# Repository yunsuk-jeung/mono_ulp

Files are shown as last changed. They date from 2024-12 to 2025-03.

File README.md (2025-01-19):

## n36tsu keyboard

- 36 keys
- PG1316S
- nice!view
- nice!nano
- wireless

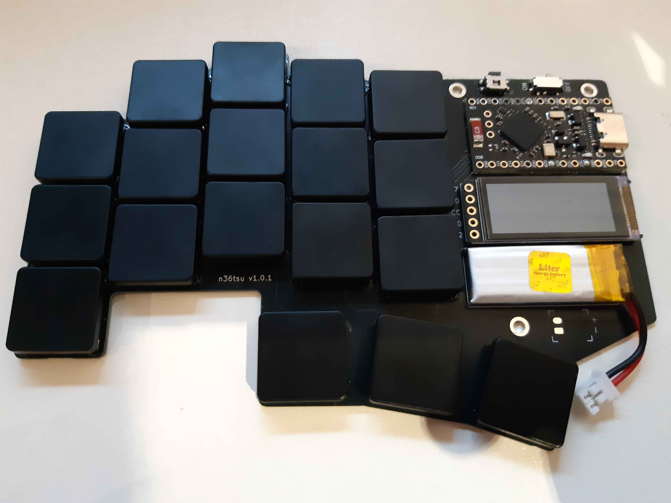
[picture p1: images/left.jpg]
left

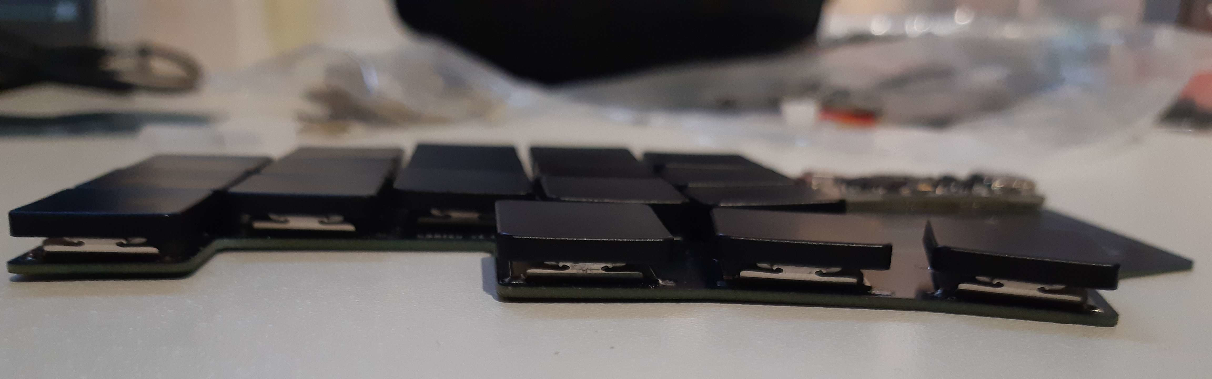
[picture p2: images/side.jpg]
side

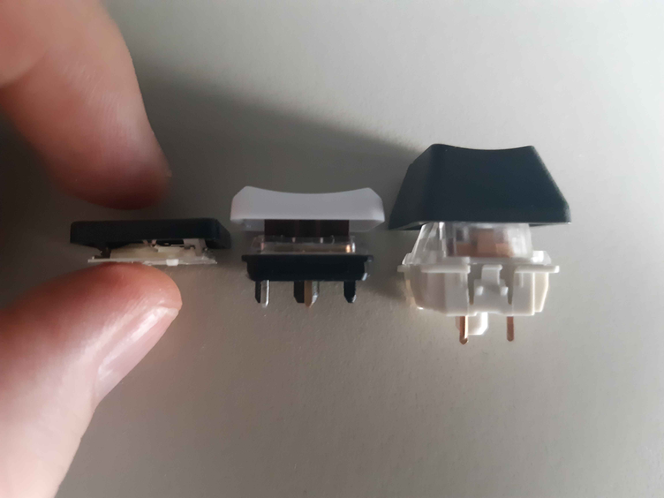
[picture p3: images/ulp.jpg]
ulp

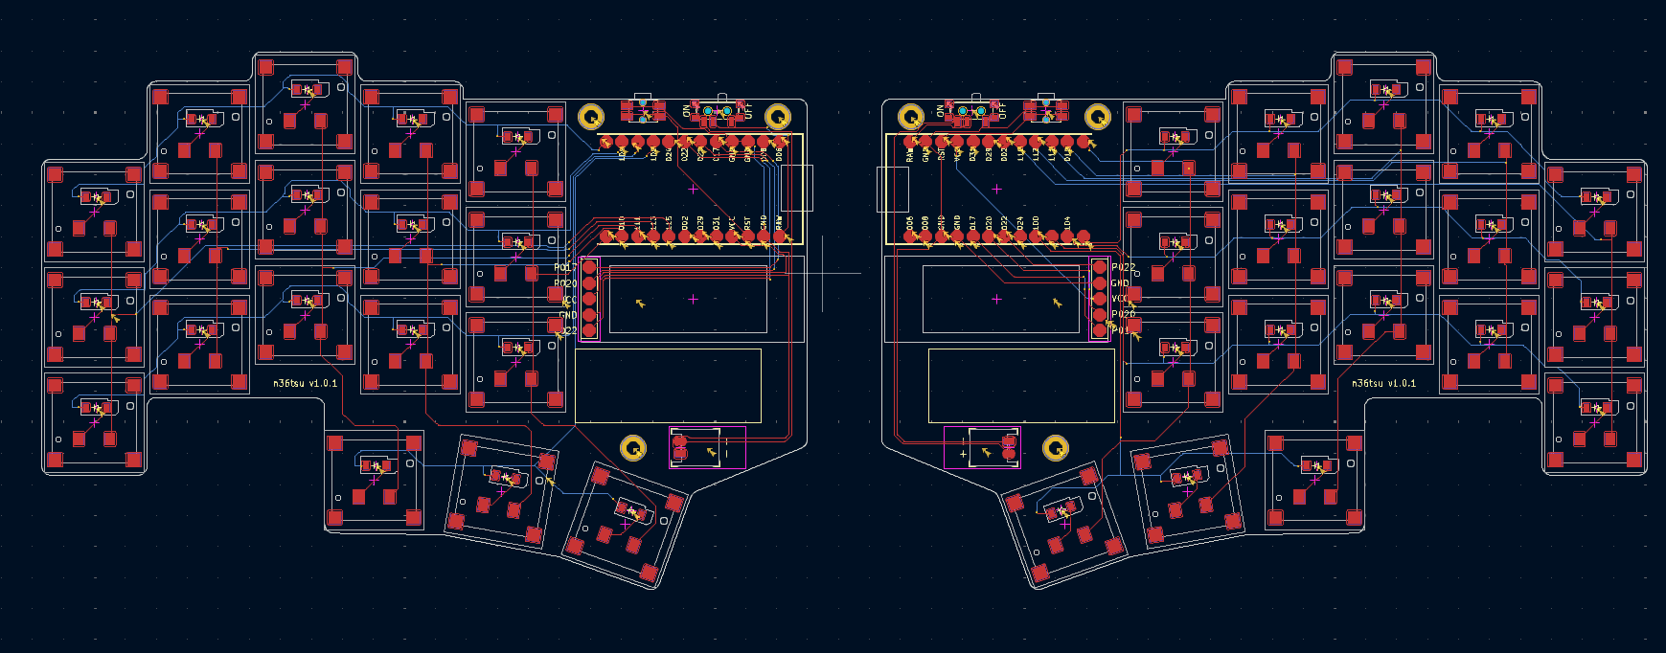
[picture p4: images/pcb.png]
PCB


## TODO

- [x] modify footprints to solder-on
- [x] verify every components orientation
- [x] add text on PCB
- [x] add case holes
- [x] wire components
- [ ] design 3D case

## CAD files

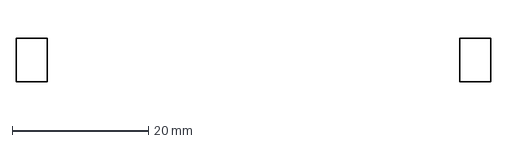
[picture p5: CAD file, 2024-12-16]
kicad/outlines/reset.dxf
69.5 x 6.40 mm

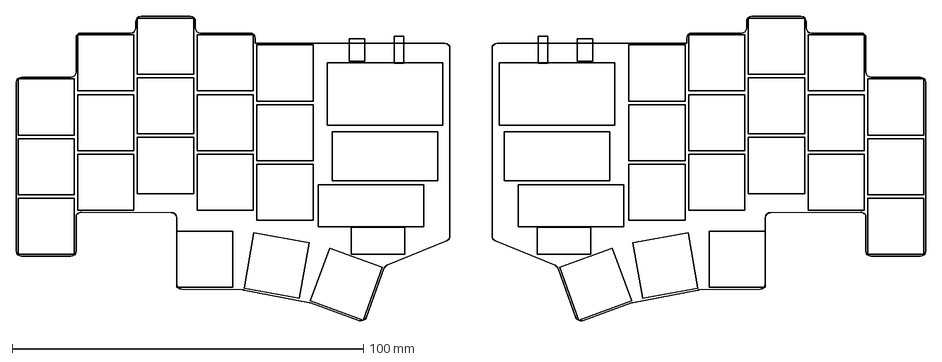
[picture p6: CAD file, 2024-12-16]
kicad/outlines/combo.dxf
259.0 x 87.0 mm

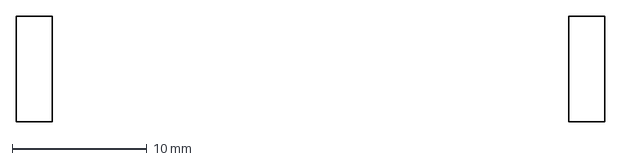
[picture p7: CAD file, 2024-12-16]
kicad/outlines/power.dxf
43.7 x 7.80 mm

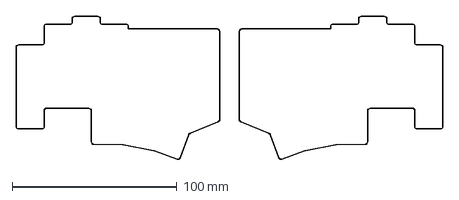
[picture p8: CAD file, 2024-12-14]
kicad/outlines/board.dxf
259.0 x 87.0 mm

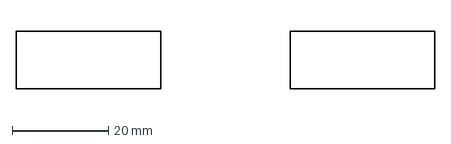
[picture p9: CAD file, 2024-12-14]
kicad/outlines/battery.dxf
87.0 x 12.0 mm

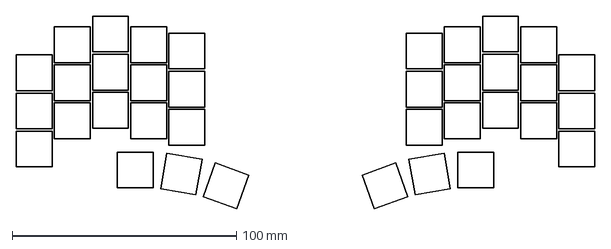
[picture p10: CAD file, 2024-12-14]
kicad/outlines/keycaps.dxf
258.0 x 86.1 mm

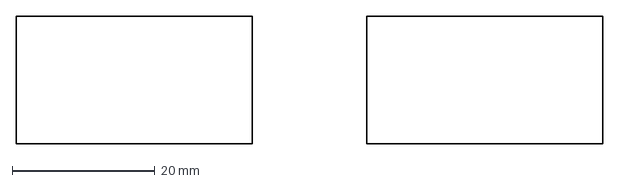
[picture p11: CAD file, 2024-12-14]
kicad/outlines/controller.dxf
82.0 x 17.8 mm

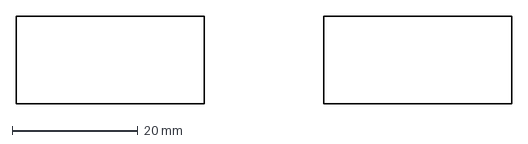
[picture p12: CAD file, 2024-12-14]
kicad/outlines/niceview.dxf
79.0 x 14.0 mm

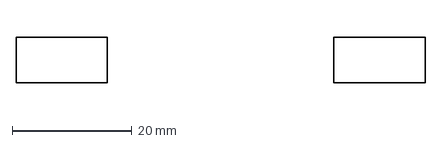
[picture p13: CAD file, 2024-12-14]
kicad/outlines/battery_connector.dxf
68.2 x 7.62 mm

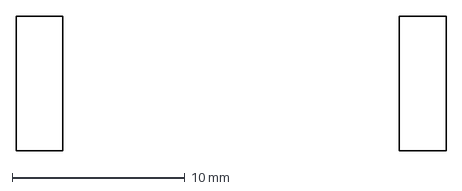
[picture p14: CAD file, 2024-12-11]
kicad/outlines/power_switch.dxf
24.9 x 7.80 mm

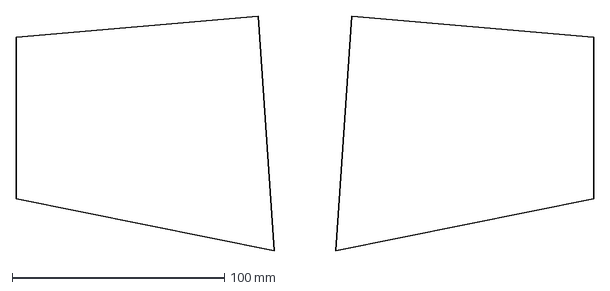
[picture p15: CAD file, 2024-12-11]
kicad/outlines/board_left.dxf
272.1 x 110.2 mm

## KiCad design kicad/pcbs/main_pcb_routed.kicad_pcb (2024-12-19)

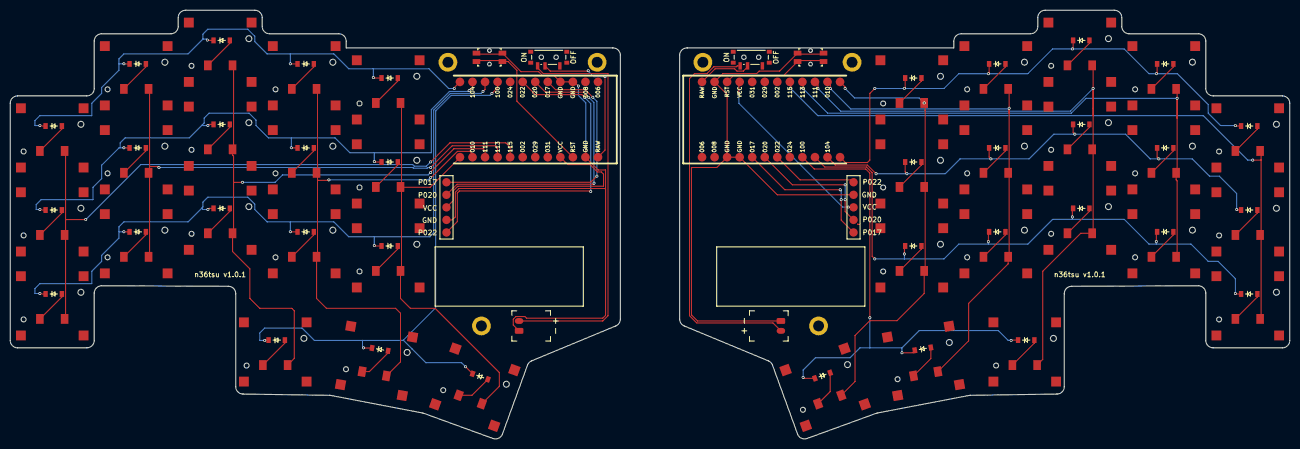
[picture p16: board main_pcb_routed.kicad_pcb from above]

Board: 2 copper layers, 259.0 x 86.8 mm, 88 parts (0 on the bottom side), 59 nets.

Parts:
D1, D2, D3, D4, D5, D6, D7, D8, D9, D10, D11, D12, D13, D14, D15, D16, D17, D18, D19, D20, D21, D22, D23, D24, D25, D26, D27, D28, D29, D30, D31, D32, D33, D34, D35, D36: diode_tht_sod123
DISP1, DISP2: display_nice_view
H1, H2, H3, H4, H5, H6: mounting_hole_plated
JST1, JST2: battery_connector_jst_ph_2
MCU1, MCU2: nice_nano
PWR1, PWR2: power_switch_smd_side
RST1, RST2: reset_switch_smd_side
S1, S2, S3, S4, S5, S6, S7, S8, S9, S10, S11, S12, S13, S14, S15, S16, S17, S18, S19, S20, S21, S22, S23, S24, S25, S26, S27, S28, S29, S30, S31, S32, S33, S34, S35, S36: CPG1316S01D02_mikeholscher

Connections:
BAT_P: JST1.2, JST2.2, PWR1.3, PWR2.3
GND: DISP1.4, DISP2.4, JST1.1, JST2.1, MCU1.3, MCU1.4, MCU1.23, MCU2.3, MCU2.4, MCU2.23, RST1.1, RST1.3, RST2.1, RST2.3
P002: MCU1.18, MCU2.18
P006: MCU1.1, MCU2.1
P008: MCU1.2, MCU2.2
P009: MCU1.13, MCU2.13, S13.2, S14.2, S15.2, S18.2, S31.2, S32.2, S33.2, S36.2
P010: MCU1.14, MCU2.14, S10.2, S11.2, S12.2, S17.2, S28.2, S29.2, S30.2, S35.2
P011: D1.1, D4.1, D7.1, D10.1, D13.1, D19.1, D22.1, D25.1, D28.1, D31.1, MCU1.10, MCU2.10
P017: DISP1.1, DISP2.1, MCU1.5, MCU2.5
P020: DISP1.2, DISP2.2, MCU1.6, MCU2.6
P022: DISP1.5, DISP2.5, MCU1.7, MCU2.7
P024: MCU1.8, MCU2.8
P029: MCU1.19, MCU2.19
P031: MCU1.20, MCU2.20
P100: D16.1, D17.1, D18.1, D34.1, D35.1, D36.1, MCU1.9, MCU2.9
P104: D2.1, D5.1, D8.1, D11.1, D14.1, D20.1, D23.1, D26.1, D29.1, D32.1, MCU1.11, MCU2.11
P106: D3.1, D6.1, D9.1, D12.1, D15.1, D21.1, D24.1, D27.1, D30.1, D33.1, MCU1.12, MCU2.12
P111: MCU1.15, MCU2.15, S7.2, S8.2, S9.2, S16.2, S25.2, S26.2, S27.2, S34.2
P113: MCU1.16, MCU2.16, S4.2, S5.2, S6.2, S22.2, S23.2, S24.2
P115: MCU1.17, MCU2.17, S1.2, S2.2, S3.2, S19.2, S20.2, S21.2
RAW: MCU1.24, MCU2.24, PWR1.2, PWR2.2
RST: MCU1.22, MCU2.22, RST1.2, RST1.4, RST2.2, RST2.4
VCC: DISP1.3, DISP2.3, MCU1.21, MCU2.21
ecolumn_arow: D8.2, S8.1
ecolumn_qrow: D9.2, S9.1
ecolumn_zrow: D7.2, S7.1
inner_default: D16.2, S16.1
middle_default: D17.2, S17.1
mirror_ecolumn_arow: D26.2, S26.1
mirror_ecolumn_qrow: D27.2, S27.1
mirror_ecolumn_zrow: D25.2, S25.1
mirror_inner_default: D34.2, S34.1
mirror_middle_default: D35.2, S35.1
mirror_outer_default: D36.2, S36.1
mirror_qcolumn_arow: D20.2, S20.1
mirror_qcolumn_qrow: D21.2, S21.1
mirror_qcolumn_zrow: D19.2, S19.1
mirror_rcolumn_arow: D29.2, S29.1
mirror_rcolumn_qrow: D30.2, S30.1
mirror_rcolumn_zrow: D28.2, S28.1
mirror_tcolumn_arow: D32.2, S32.1
mirror_tcolumn_qrow: D33.2, S33.1
mirror_tcolumn_zrow: D31.2, S31.1
mirror_wcolumn_arow: D23.2, S23.1
mirror_wcolumn_qrow: D24.2, S24.1
mirror_wcolumn_zrow: D22.2, S22.1
outer_default: D18.2, S18.1
qcolumn_arow: D2.2, S2.1
qcolumn_qrow: D3.2, S3.1
qcolumn_zrow: D1.2, S1.1
rcolumn_arow: D11.2, S11.1
rcolumn_qrow: D12.2, S12.1
rcolumn_zrow: D10.2, S10.1
tcolumn_arow: D14.2, S14.1
tcolumn_qrow: D15.2, S15.1
tcolumn_zrow: D13.2, S13.1
wcolumn_arow: D5.2, S5.1
wcolumn_qrow: D6.2, S6.1
wcolumn_zrow: D4.2, S4.1

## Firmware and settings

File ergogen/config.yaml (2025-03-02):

meta:
  engine: 4.1.0
  version: 0.0.1
  author: n1tsu

units:
  # keys
  ks: 16
  kp: 1
  kx: ks+kp
  hkx: 0.5kx
  pp: 4.9 #pcb padding
  pf: 3
  # px: 0
  qcol_stagger: 0kx
  wcol_stagger: 0.625 kx
  ecol_stagger: 0.125U
  rcol_stagger: -0.375U
  tcol_stagger: -0.125U
  thumb_splay: 0
  mirror_splay: -15
  mirror_dist: 60
  # mirror_splay: 0
  # mirror_dist: 80

  # case
  case_edge_size: 0

  # screw
  sr: 1.1 # M2 screws radius
  sd: sr * 2
  sp: sr * 2 #screw padding

  # components
  components_padding: 4
  nicenano_width: 17.78
  nicenano_height: 33
  battery_width: 12
  battery_height: 30
  niceview_width: 14
  niceview_height: 30
  battery_connector_width: 8.5 # !
  battery_connector_height: 3 # !
  power_width: 8.5
  power_height: 3
  reset_width: 8
  reset_height: 3.5

points:
  zones:
    matrix:
      key:
        spread: ks + kp
        tags: "keys"
      anchor.shift: [100, -100]
      columns:
        qcol:
          key:
            stagger: qcol_stagger
            column_net: D05
        wcol.key.stagger: wcol_stagger
        ecol.key.stagger: ecol_stagger
        rcol.key.stagger: rcol_stagger
        tcol.key.stagger: tcol_stagger
      rows:
        zrow.padding: ks + kp
        arow.padding: ks + kp
        qrow:
          padding: ks + kp
          row_net: D01
          mirror.row_net: D04

    thumb:
      key:
        tags: "keys"
        spread: ks+kp
        padding: ks+kp
      anchor:
        ref: matrix_rcol_zrow
        shift: [0, -ks-kp]
      columns:
        inner:
        middle.key:
          shift: [0, tcol_stagger]
        outer.key:
          shift: [0, tcol_stagger+tcol_stagger]

    helper_qcol_zrow_right_bottom:
      key.tags:
        - helper
      anchor:
        ref: matrix_qcol_zrow
        shift: [kx, -50]

    helper_thumb_inner_left_bottom:
      key.tags:
        - helper
      anchor:
        ref: thumb_inner
        shift: [-hkx-pp, -hkx-pp]
        rotate: 90

    helper_qcol_zrow_thumb_inter:
      key.tags:
        - helper
      anchor:
        - aggregate:
            method: intersect
            parts:
              - ref: helper_qcol_zrow_right_bottom
              - ref: helper_thumb_inner_left_bottom

    helper_tcol_qrow_unrotated:
      key.tags:
        - helper
      anchor:
        ref: matrix_tcol_qrow
        rotate: -mirror_splay

    helper_tcol_qrow_directing_right:
      key.tags:
        - helper
      anchor:
        ref: matrix_tcol_qrow
        shift: [(hkx+pp), (hkx+pp)]
        rotate: -90-mirror_splay

    center_line:
      key.tags:
        - helper
      anchor:
        ref: helper_tcol_qrow_unrotated
        shift: [0.5 mirror_dist, 50]
        rotate: 180

    controller_top_rotated:
      key.tags:
        - helper
      anchor:
        - aggregate:
            method: intersect
            parts:
              - ref: helper_tcol_qrow_directing_right
              - ref: center_line

    controller_top:
      key.tags:
        - helper
      anchor:
        ref: controller_top_rotated
        rotate: -mirror_splay

    controller_center:
      key.tags:
        - helper
      anchor:
        ref: controller_top
        shift: [0, -0.5 nicenano_height -0.5 + tcol_stagger-3]

    helper_thumb_outer_directing_right:
      key.tags:
        - helper
      anchor:
        ref: thumb_outer
        shift: [hkx+pp, hkx]
        rotate: -90-mirror_splay

    power_rotated:
      key.tags:
        - helper
      anchor:
        - aggregate:
            method: intersect
            parts:
              - ref: helper_thumb_outer_directing_right
              - ref: center_line

    power_center_bottom:
      key.tags:
        - helper
      anchor:
        ref: power_rotated
        rotate: -mirror_splay

    power_center:
      key.tags:
        - helper
      anchor:
        ref: power_center_bottom
        shift: [0, 0.5 power_height + 0.5]

    battery_center:
      key.tags:
        - helper
      anchor:
        ref: power_center
        shift: [0, 8.5]
        rotate: 90

    reset_center:
      key.tags:
        - helper
      anchor:
        ref: thumb_outer
        shift: [2, hkx + pp + reset_height]

    sc_tl:
      key.tags:
        - screw
      anchor:
        - ref: matrix_qcol_qrow
          shift: [0, hkx+pp]

    sc_tm:
      key.tags:
        - screw
      anchor:
        - ref: matrix_ecol_qrow
          shift: [0, hkx+pp-sp]
    sc_rm:
      key.tags:
        - screw
      anchor:
        - ref: matrix_tcol_qrow
          shift: [hkx+2sp, hkx-sp]
    sc_rb:
      key.tags:
        - screw
      anchor:
        - ref: thumb_outer
          shift: [hkx+pp-1.2sp, -hkx-pp+1.2sp]
    sc_rb2:
      key.tags:
        - screw
      anchor:
        - ref: thumb_inner
          shift: [-hkx-pp+1.2sp, -hkx-pp+1.2sp]
    sc_lb:
      key.tags:
        - screw
      anchor:
        - ref: matrix_qcol_zrow
          shift: [-hkx-pp+0.9pf, -hkx-pp+0.9pf]
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

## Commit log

2024-12-10 Update PG1316 footprint
2024-12-11 Add README, kicad and image
    [battery.dxf, battery_connector.dxf, board.dxf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]
2024-12-12 Adjust PCB component positions
    [battery.dxf, battery_connector.dxf, board.dxf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]
2024-12-12 Add text footprint
2024-12-14 Remove pcb border
    [battery.dxf, battery_connector.dxf, board.dxf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]
2024-12-14 Route left PCB
    [main_pcb.kicad_pcb, main_pcb_routed.kicad_pcb]
2024-12-16 Modify routing
    [combo.dxf, main_pcb.kicad_pcb, main_pcb_routed2.kicad_pcb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]
2024-12-17 Complete PCB wiring
    [main_pcb_routed.kicad_pcb, main_pcb_routed2.kicad_pcb]
2024-12-17 Update PCB wiring (DRC)
    [main_pcb_routed.kicad_pcb]
2024-12-19 Modify PCB
    [main_pcb_routed.kicad_pcb]
2025-01-07 Update PCB image
2025-02-28 added reset switch
2025-02-28 added footprint for battery
2025-03-01 fixed battery_pad
2025-03-01 added screw
2025-03-02 added case outline
